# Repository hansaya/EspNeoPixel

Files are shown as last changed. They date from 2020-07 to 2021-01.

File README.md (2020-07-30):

# EspNeoPixel

Esp32 based neo pixel driver designed to work with WLED. 

# Thoughts behind my design
I recently discovered that [wled project](https://github.com/Aircoookie/WLED) works with [hyperion](https://hyperion-project.org/) and sparked my interest in building a unified system to tick off all the requirements. From previous experience with neo pixels, I knew I had to make sure to have a good power supply and a good logic level conversion to run the leds reliably. Power supply is the biggest thing to tackle and for it I have tried many off the shelve converters but most either bulky or cannot run at specified rating. You could buy a AC to DC converts thats rated for the led without using dc-dc converter but either they are expensive or have to compromise in quality. I decided to design my board around ~20V input because I have many old laptop power bricks collecting dust that can handle at least 100W each. They are safe and can find in many shape and sizes. If you don't have one, you can easily obtain one through ebay. 

Features:
* Buck converter, 8-24V input to 5v or 12v output to drive the led strips.
* Up to 10A output current.
* Level converter to drive the data and clock singles at 5v.
* Button connected to GPIO0. This can be used within wled to turn off the output.
* Capability to turn off the output using wled relay output.
* Push in terminal connectors for quick connections.

# Board

Use zip file within /cam folder to fabricate the board using your favorite pcb house. Bom contains the parts list. Please note, I have not listed out all parts since I had most 0603 jelly beans parts at home. Use the schematic to get the full list.

Enjoy!

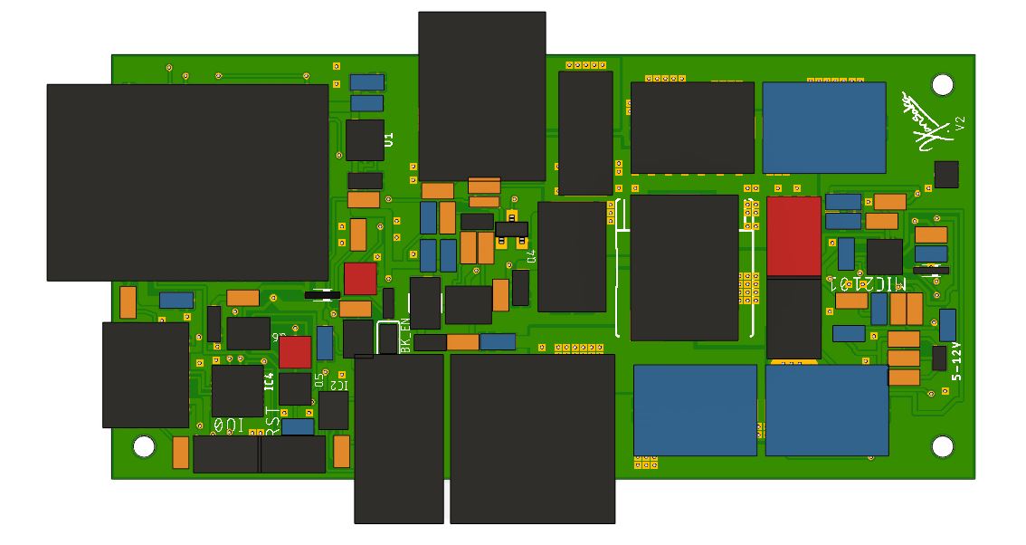
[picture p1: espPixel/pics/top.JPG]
Top side of the board

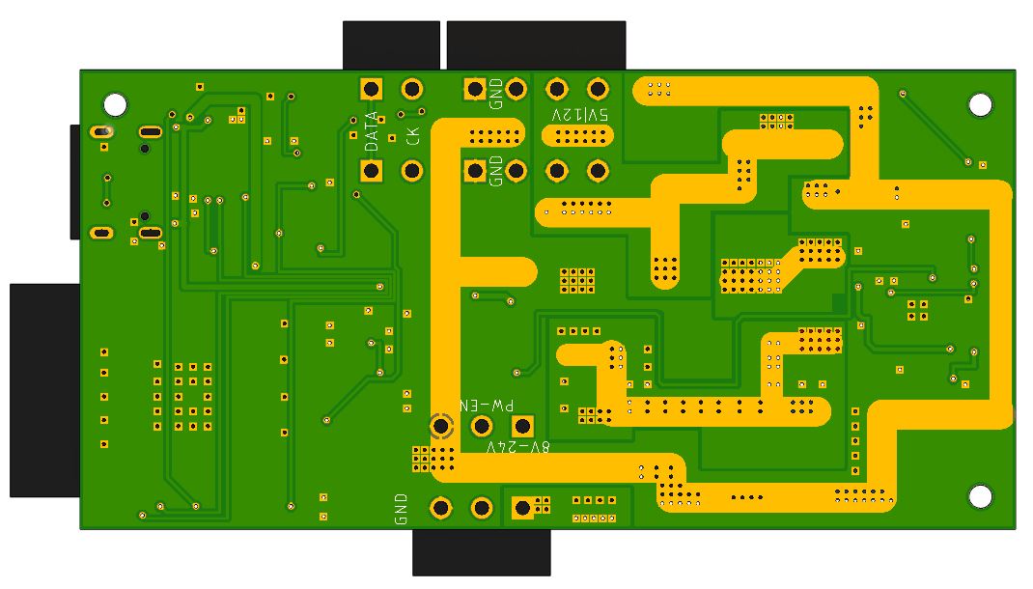
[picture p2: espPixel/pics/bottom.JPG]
Bottom side of the board

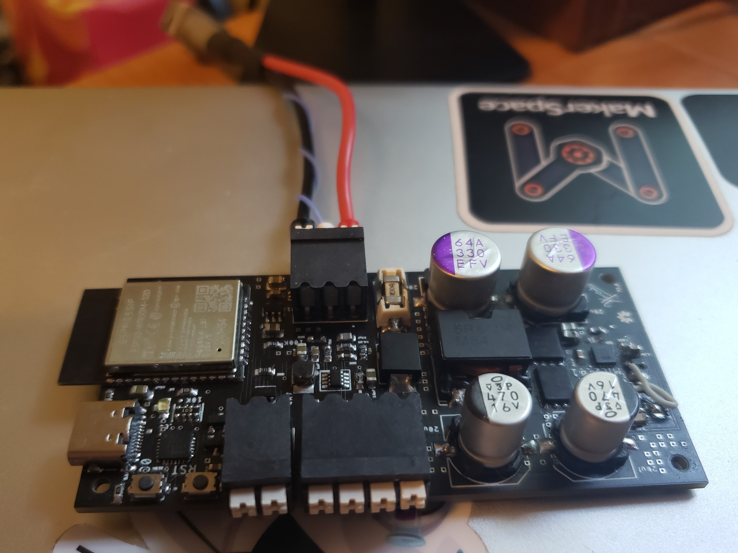
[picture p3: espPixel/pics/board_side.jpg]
Populated board


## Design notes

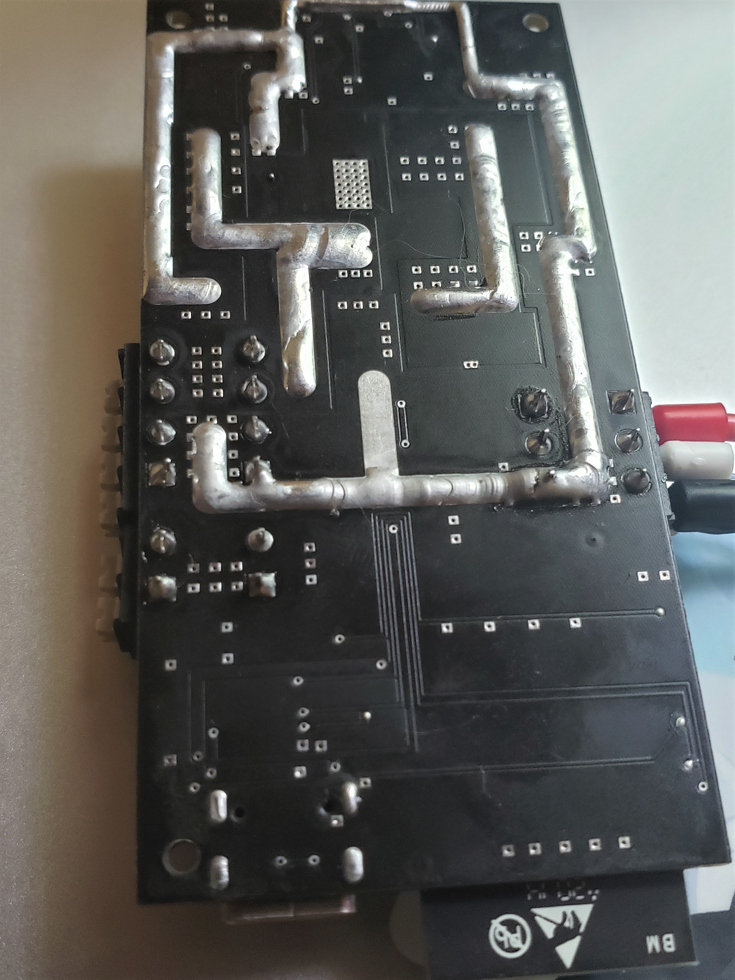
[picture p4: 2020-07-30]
espPixel/pics/board_back.jpg

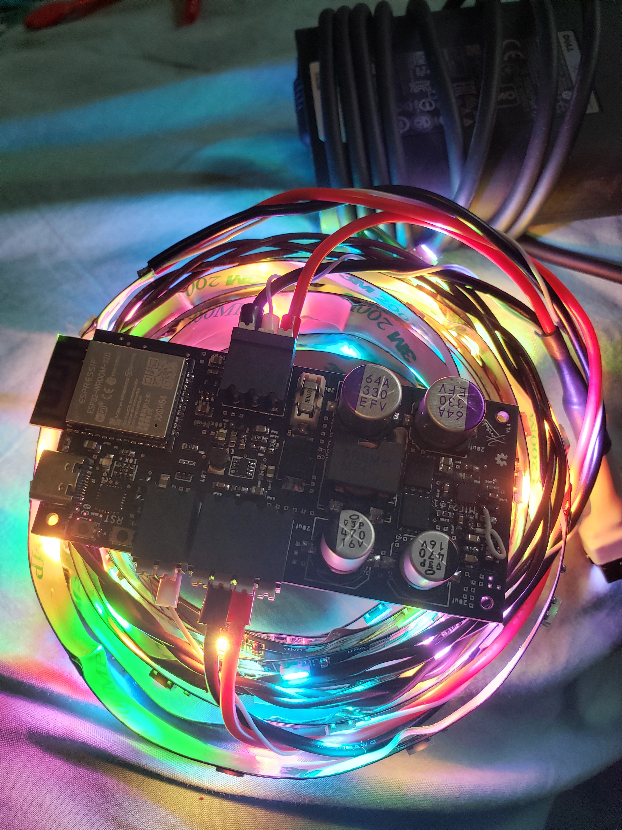
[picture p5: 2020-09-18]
espPixel/pics/running_wled.jpg

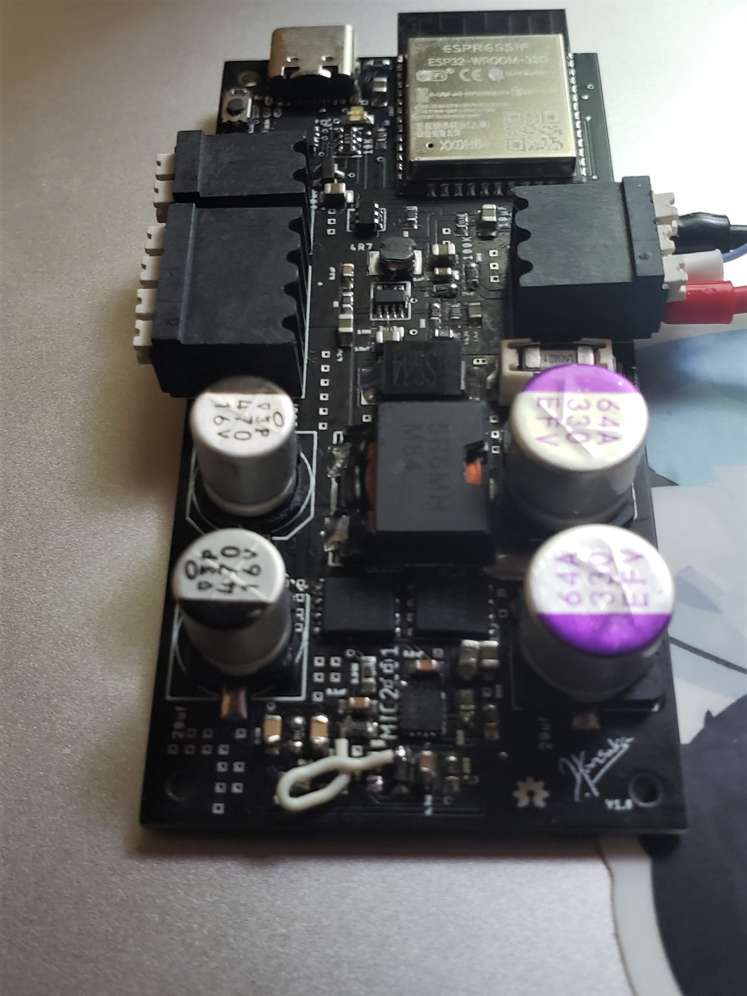
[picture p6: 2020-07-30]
espPixel/pics/board_top.jpg

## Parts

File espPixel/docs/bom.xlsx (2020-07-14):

Part name | Part number | price | location
Level shifter | 74LVC1T45W6-7 | 0.27 | https://www.digikey.com/product-detail/en/diodes-incorporated/74LVC1T45W6-7/74LVC1T45W6-7DICT-ND/8283861
4pin connector | TBLH10-350-04BK | 1.55 | https://www.digikey.com/product-detail/en/TBLH10-350-04BK/102-TBLH10-350-04BK-ND/10441921/?itemSeq=331108432
3pin connector | TBLH10-350-03BK | 1.33 | https://www.digikey.com/product-detail/en/cui-devices/TBLH10-350-03BK/102-TBLH10-350-03BK-ND/10442185
2pin connector | TBLH10-350-02BK | 1.02 | https://www.digikey.com/product-detail/en/TBLH10-350-02BK/102-TBLH10-350-02BK-ND/10442183/?itemSeq=331108581
649ohm | RMCF0603FT649RCT-ND‎ | 0.00292 | https://www.digikey.com/product-detail/en/RMCF0603FT649R/RMCF0603FT649RCT-ND/2418115/?itemSeq=331108552
3.48K ohm | RMCF0603FT3K48 | 0.1 | https://www.digikey.com/product-detail/en/RMCF0603FT3K48/RMCF0603FT3K48CT-ND/1943027/?itemSeq=331108413
9.09K ohm | RMCF0603FT9K09 | 0.1 | https://www.digikey.com/product-detail/en/stackpole-electronics-inc/RMCF0603FT9K09/RMCF0603FT9K09CT-ND/1943054
Inductor 4.7UH | CEP125NP 4.7UH | 11.7/10 | https://www.aliexpress.com/item/32839370463.html?spm=a2g0s.9042311.0.0.35f14c4dAlGctQ
ESP32 | ESP32-WROOM-32D | 2.37
1808 Fuse holder | 1808/2410 fuse holder | 0.2 | https://www.aliexpress.com/item/4000013163243.html?spm=a2g0s.9042311.0.0.4fa64c4dJv0TfD
1808 Fuse | 1808 Fuse | 0.2
5v Buck converter | MP2315 | 0.2 | https://www.aliexpress.com/item/32899141853.html
3.3 LDO | AP2112-3.3 | 0.47 | https://www.digikey.com/product-detail/en/diodes-incorporated/AP2112K-3-3TRG1/AP2112K-3-3TRG1DICT-ND/4505257
10A Buck converter | MIC2101 | 1.1 | https://www.digikey.com/product-detail/en/microchip-technology/MIC2101YML-TR/576-4154-1-ND/3681253
Push Buttons | 2Pin 3X4MM Tactile | 0.05 | https://www.ebay.com/itm/50PCS-SMD-2Pin-3X4MM-Tactile-Tact-Push-Button-Micro-Switch-Momentary/114266539434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
USB-C port | USB 3.1 Type C 16 Pin | 0.2 | https://www.ebay.com/itm/50PCS-USB-3-1-Type-C-4-Legs-16-Pin-Female-Socket-PCB-Solder-Connector-SMT/183702842042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
USB to Serial | CP2104 | 1.5 | https://www.digikey.com/product-detail/en/silicon-labs/CP2104-F03-GMR/336-4146-2-ND/4069045
10K Resistor array | CAY16-103J4LF | 0.1 | https://www.digikey.com/product-detail/en/bourns-inc/CAY16-103J4LF/CAY16-103J4LFCT-ND/3437832
Total |  | 10.76292

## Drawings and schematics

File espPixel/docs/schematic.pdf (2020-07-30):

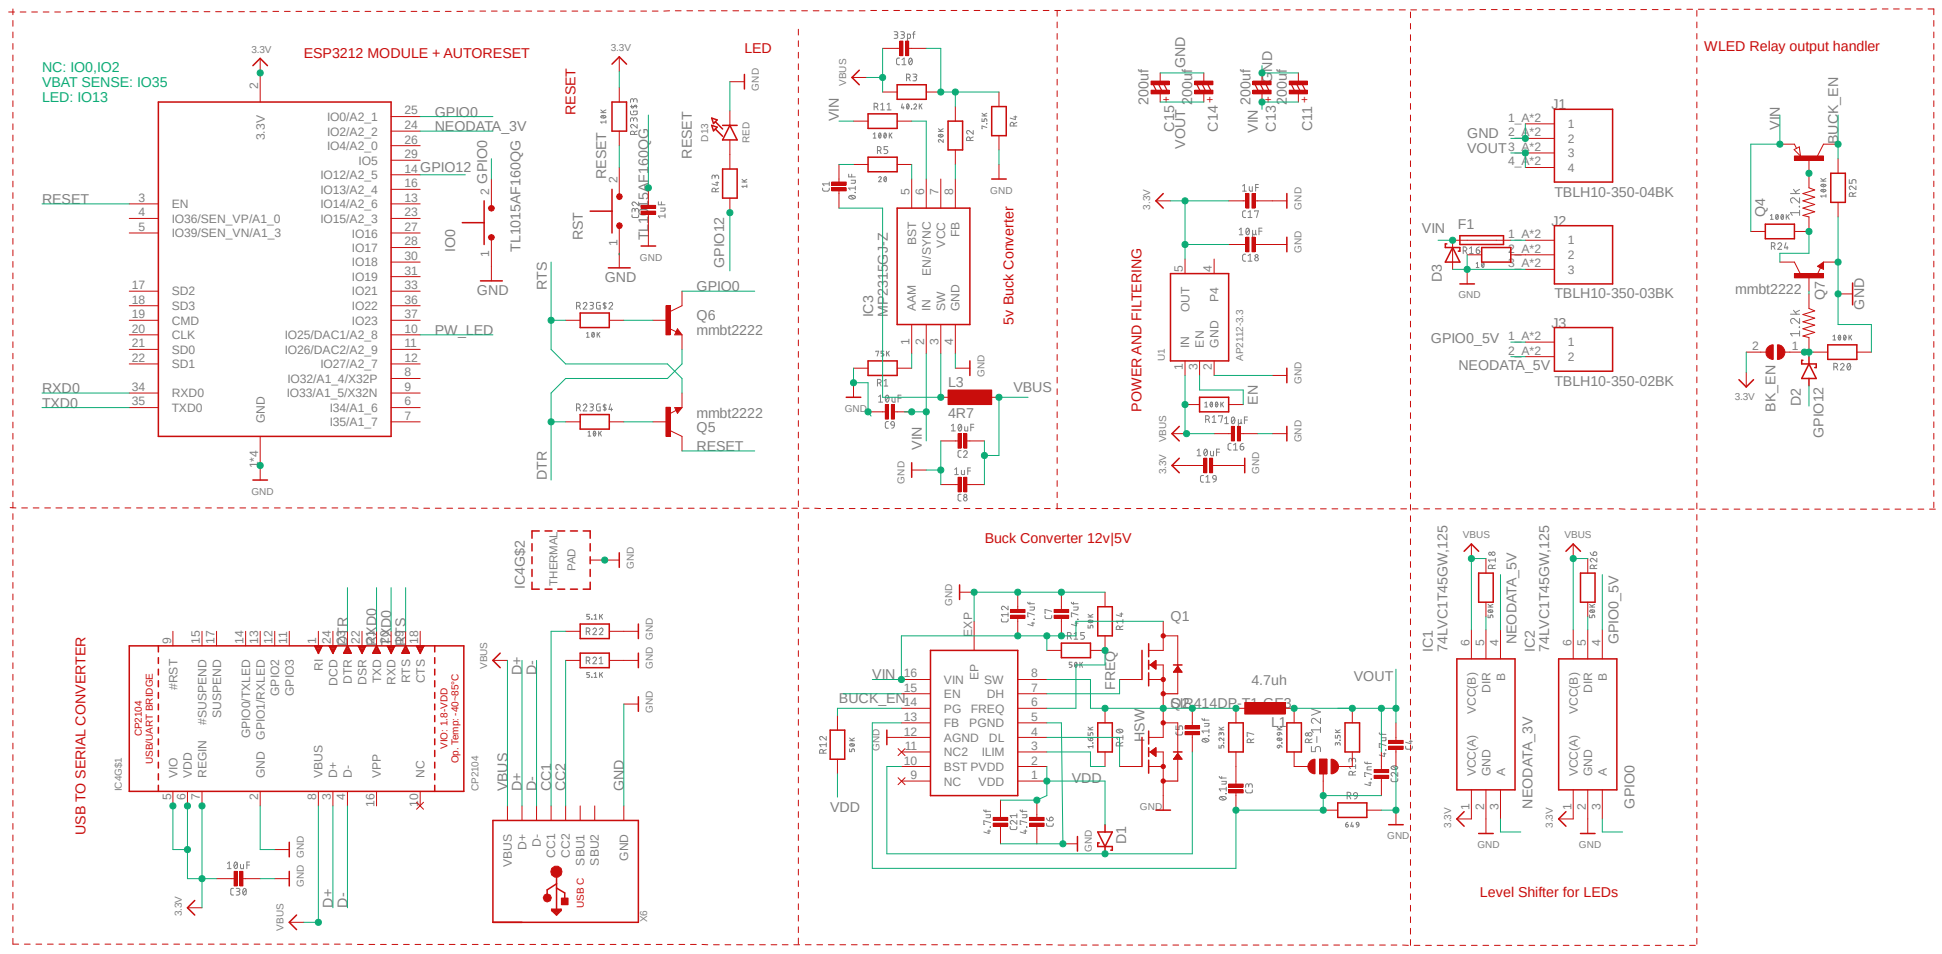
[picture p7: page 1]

4IC2 GND GND GND GND

WLED Relay output handler +

+ CP2104 USB/UART BRIDGE VIO: 1.8-VDD Op. Temp: -40~85°C USB C

9 NC 10 GPIO3 11 GPIO2 12 DCD 24 DTR 23 DSR 22 TXD 21 RXD 20 RTS 19 CTS 18 SUSPEND 17 VPP 16 #SUSPEND 15 GPIO0/TXLED 14 GPIO1/RXLED 13 IC4G$1 THERMAL PAD IC4G$2 D+D- VBUS CC1 GND SBU1 CC2 SBU2 X6 D13 1 2 RST 1 2 IO0 Q4

Level Shifter for LEDs

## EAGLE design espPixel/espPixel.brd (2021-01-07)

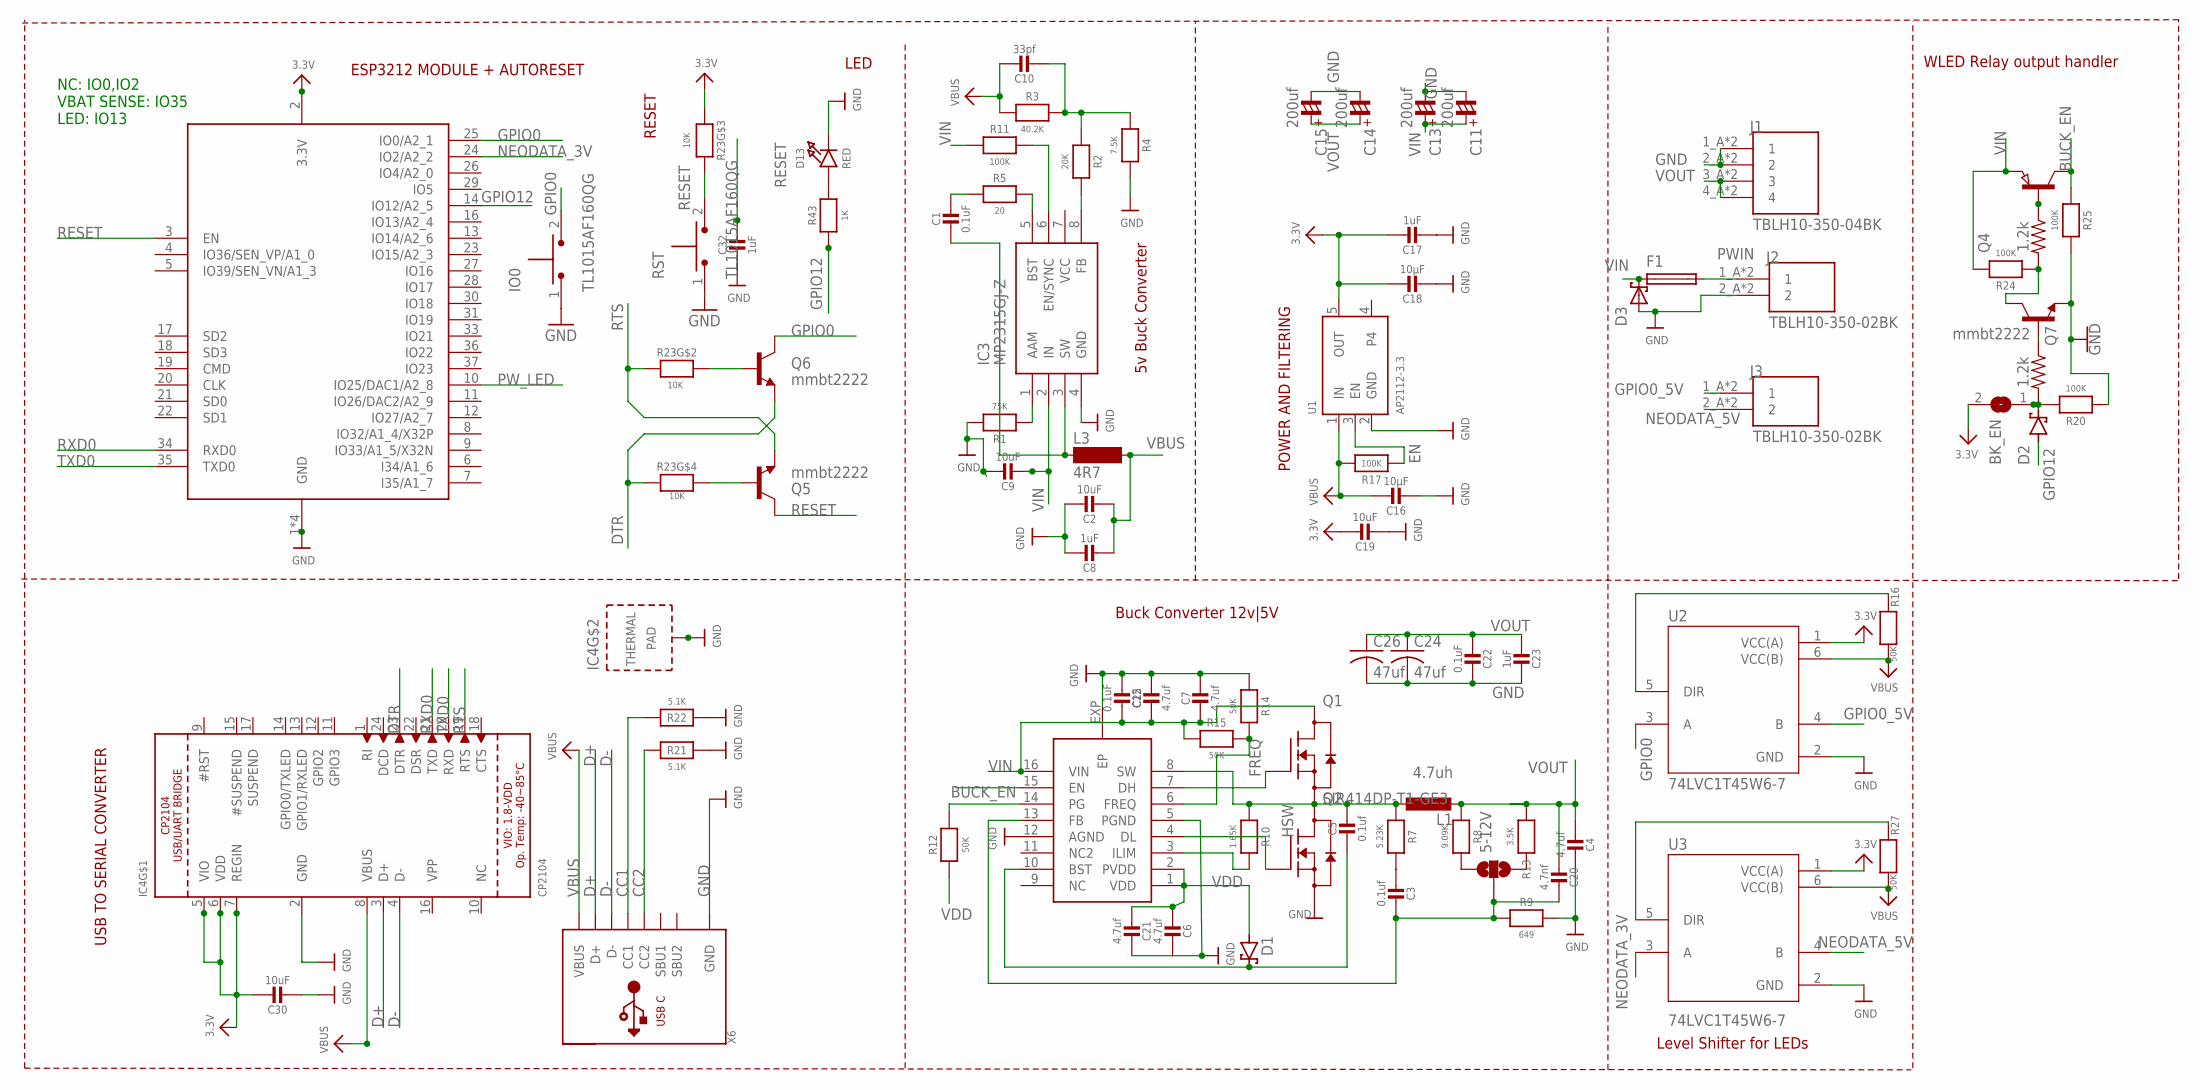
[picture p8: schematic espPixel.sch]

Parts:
5-12V: JUMPER-SMT_3_NO_NO-SILK; SMT-JUMPER_3_NO_NO-SILK
BK_EN: SJ
C1, C22, C25: 0.1uF; 0603-NO@1
C2: 10uF; 0603-NO@1
C3, C5: 0.1uf; 0603-NO@1
C4, C7, C12: 4.7uf; 0805_10MGAP
C6, C21: 4.7uf; 0603-NO@1
C8, C17, C23, C32: 1uF; 0603-NO@1
C9: 10uF; 0805_10MGAP
C10: 33pf; 0603-NO@1
C11, C13, C14, C15: 200uf; CSV-E/F
C16, C18: 10µF; 0805-NO
C19, C30: 10uF; 0805-NO
C20: 4.7nf; 0603-NO@1
C24, C26: 47uf; C3225
D1, D2: BAT60J; SOD323_ST
D3: SCHOTTKY-DIODESMC; SMC
D13: RED; CHIPLED_0805_NOOUTLINE
F1: SMD-MICRO-FUSE-BLOCK; OMNIBLOK
IC3: MP2315GJ-Z; SOT65P280X100-8N
IC4: CP2104; QFN24_4MM_SMSC
IO0: TL1015AF160QG; SW_TL1015AF160QG
J1: TBLH10-350-04BK; CUI_TBLH10-350-04BK
J2, J3: TBLH10-350-02BK; CUI_TBLH10-350-02BK
L1: 4.7uh; CEP125
L3: 4R7; MS50
Q1, Q2: SIR414DP-T1-GE3; TRANS_SQJ461EP-T1-GE3
Q4: PNP-TRANSISTOR_SOT23; SOT23
Q5, Q6, Q7: mmbt2222; SOT23-3
R1: 75K; 0603-NO
R2: 20K; 0603-NO
R3: 40.2K; 0603-NO
R4: 7.5K; 0603-NO
R5: 20; 0603-NO
R6, R19: 1.2k; 0603
R7: 5.23K; 0603-NO
R8: 9.09K; 0603-NO
R9: 649; 0603-NO
R10: 1.65K; 0603-NO
R11, R17, R20, R24, R25: 100K; 0603-NO
R12, R14, R15, R16, R27: 50K; 0603-NO
R13: 3.5K; 0603-NO
R21, R22: 5.1K; 0603-NO
R23: 10K; RESPACK_4X0603
R43: 1K; 0603-NO
RST: TL1015AF160QG; SW_TL1015AF160QG
U1: AP2112-3.3; SOT23-5
U2, U3: 74LVC1T45W6-7; SOT95P285X140-6N
U$1: MIC2101QFN16; QFN16
X6: USB_C; USB_C_CUSB31-CFM2AX-01-X
X8: ESP32_WROOM32_SKINNY; WROOM32_SKINNY

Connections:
3.3V: BK_EN.2, C17.1, C18.1, C19.1, C30.1, IC4.5 (VIO), IC4.6 (VDD), IC4.7 (REGIN), R23.3 (1), U1.5 (OUT), U2.1 (VCC(A)), U3.1 (VCC(A)), X8.2 (3.3V)
BUCK_EN: Q4.3 (C), R25.1, U$1.15 (EN)
CC1: R22.2, X6.A5 (CC1)
CC2: R21.2, X6.B5 (CC2)
D+: IC4.3 (D+), X6.A6 (D+), X6.B6 (D+)
D-: IC4.4 (D-), X6.A7 (D-), X6.B7 (D-)
DTR: IC4.23 (DTR), Q6.2 (E), R23.4 (1)
EN: R17.1, U1.3 (EN)
FREQ: R14.2, R15.2, U$1.6 (FREQ)
GND: C2.1, C4.1, C6.1, C7.1, C8.1, C9.1, C11.-, C12.1, C13.-, C14.-, C15.-, C16.2, C17.2, C18.2, C19.2, C21.1, C22.1, C23.1, C24.2, C25.2, C26.2, C30.2, C32.2, D3.A, D13.C, IC3.4 (GND), IC4.2 (GND), IC4.THERM (TP), IO0.1, J1.1_A (1), J1.1_B (1), J1.2_A (2), J1.2_B (2), J2.2_A (2), J2.2_B (2), Q2.1 (S), Q2.2 (S), Q2.3 (S), Q7.2 (E), R1.2, R4.2, R9.2, R14.1, R20.1, R21.1, R22.1, R25.2, RST.1, U1.2 (GND), U2.2 (GND), U3.2 (GND), U$1.5 (PGND), U$1.12 (AGND), U$1.EXP (EP), X6.A1B12 (GND), X6.B1A12 (GND), X8.1 (GND), X8.15 (GND), X8.38 (GND), X8.P$1 (GND)
GPIO0: IO0.2, Q6.3 (C), U2.3 (A), X8.25 (IO0/A2_1)
GPIO0_5V: J3.1_A (1), J3.1_B (1), U2.4 (B)
GPIO12: D2.A, R43.1, X8.14 (IO12/A2_5)
HSW: C5.1, L1.1, Q1.1 (S), Q1.2 (S), Q1.3 (S), Q2.5 (D), Q2.6 (D), Q2.7 (D), Q2.8 (D), Q2.9 (D), R7.1, R10.1, U$1.8 (SW)
unnamed: IC3.8 (FB), R2.2
unnamed: C10.2, R2.1, R3.2, R4.1
unnamed: IC3.5 (BST), R5.2
unnamed: IC3.1 (AAM), R1.1
unnamed: IC3.6 (EN/SYNC), R11.2
unnamed: C1.1, R5.1
unnamed: R12.2, U$1.14 (PG)
unnamed: C3.2, R7.2
unnamed: BK_EN.1, D2.C, R6.2, R20.2
unnamed: R27.1, U3.5 (DIR)
unnamed: 5-12V.2, C3.1, C20.1, R9.1, U$1.13 (FB)
unnamed: Q2.4 (G), U$1.4 (DL)
unnamed: Q1.4 (G), U$1.7 (DH)
unnamed: R10.2, U$1.3 (ILIM)
unnamed: C5.2, D1.C, U$1.10 (BST)
unnamed: 5-12V.1, R8.2
unnamed: 5-12V.3, R13.2
unnamed: D13.A, R43.2
unnamed: Q7.1 (B), R6.1
unnamed: Q4.1 (B), R19.1
unnamed: C1.2, IC3.3 (SW), L3.1
unnamed: Q7.3 (C), R19.2, R24.1
unnamed: R16.1, U2.5 (DIR)
unnamed: Q5.1 (B), R23.5 (2)
unnamed: Q6.1 (B), R23.7 (2)
NEODATA_3V: U3.3 (A), X8.24 (IO2/A2_2)
NEODATA_5V: J3.2_A (2), J3.2_B (2), U3.4 (B)
PWIN: F1.P$1 (1), J2.1_A (1), J2.1_B (1)
PW_LED: X8.10 (IO25/DAC1/A2_8)
RESET: C32.1, Q5.3 (C), R23.6 (2), RST.2, X8.3 (EN)
RTS: IC4.19 (RTS), Q5.2 (E), R23.2 (1)
RXD0: IC4.21 (TXD), X8.34 (RXD0)
TXD0: IC4.20 (RXD), X8.35 (TXD0)
VBUS: C2.2, C8.2, C10.1, C16.1, IC4.8 (VBUS), L3.2, R3.1, R16.2, R17.2, R27.2, U1.1 (IN), U2.6 (VCC(B)), U3.6 (VCC(B)), X6.A4B9 (VBUS), X6.B4A9 (VBUS)
VDD: C6.2, C21.2, D1.A, R12.1, U$1.1 (VDD), U$1.2 (PVDD)
VIN: C7.2, C9.2, C11.+, C12.2, C13.+, C25.1, D3.C, F1.P$2 (2), IC3.2 (IN), Q1.5 (D), Q1.6 (D), Q1.7 (D), Q1.8 (D), Q1.9 (D), Q4.2 (E), R11.1, R15.1, R24.2, U$1.16 (VIN)
VOUT: C4.2, C14.+, C15.+, C20.2, C22.2, C23.2, C24.1, C26.1, J1.3_A (3), J1.3_B (3), J1.4_A (4), J1.4_B (4), L1.2, R8.1, R13.1

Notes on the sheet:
5v Buck Converter
POWER AND FILTERING
ESP3212 MODULE + AUTORESET
NC: IO0,IO2 VBAT SENSE: IO35 LED: IO13
USB TO SERIAL CONVERTER
RESET
LED
Buck Converter 12v|5V
Level Shifter for LEDs
WLED Relay output handler

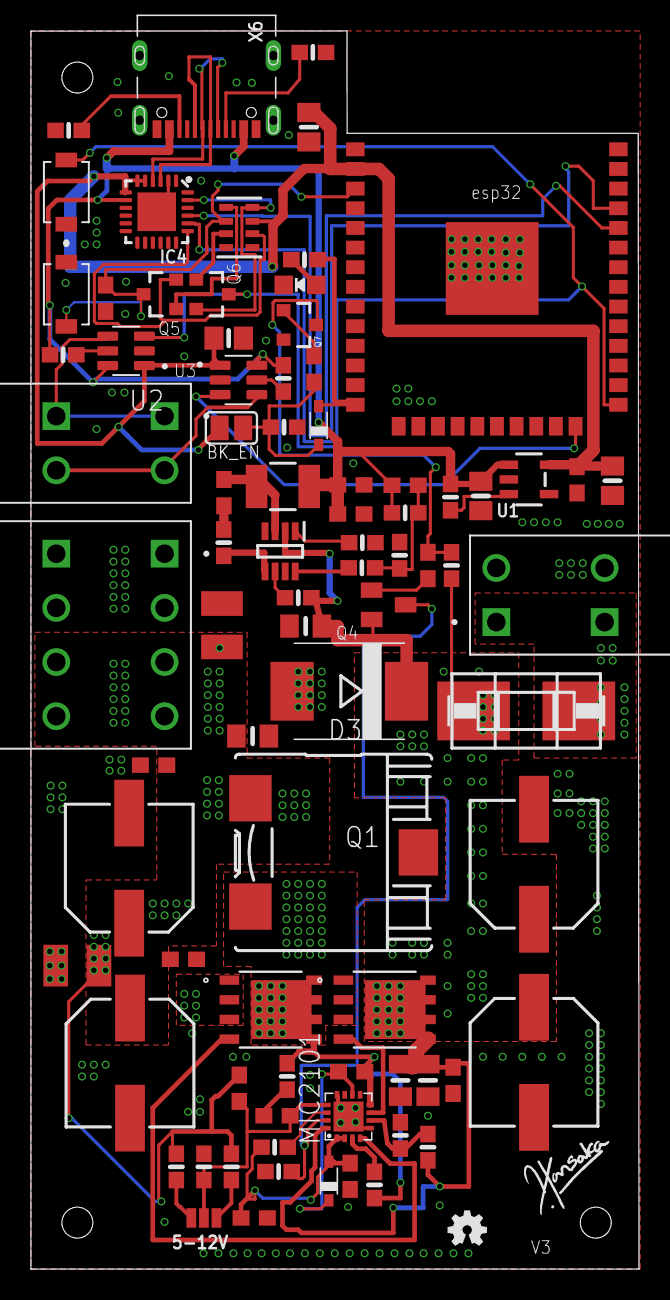
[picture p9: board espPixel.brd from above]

Board: 2 copper layers, 39.3 x 80.0 mm, 84 parts (0 on the bottom side), 50 nets.

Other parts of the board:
U$30: OSHW-LOGO-MINI
U$33: SIGNATURE

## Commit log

2020-07-01 final board files
    [espPixel.brd, espPixel.sch]
2020-07-14 bug fix
    [espPixel.brd, espPixel.sch]
2020-07-14 Text clean up
    [espPixel.brd, espPixel.sch]
2020-07-14 parts list update
    [pibom.xlsx]
2020-07-15 ability to turn off the output
    [espPixel.brd, espPixel.sch]
2020-07-16 bigger caps
    [espPixel.brd, espPixel.sch]
2020-07-22 clean up
    [espPixel.brd, espPixel.sch]
2020-07-30 finalizing the design
    [espPixel.brd, espPixel.sch]
2020-09-18 More filter caps
    [espPixel.brd, espPixel.sch]
2021-01-07 v3 more compact size
    [espPixel.brd, espPixel.sch]

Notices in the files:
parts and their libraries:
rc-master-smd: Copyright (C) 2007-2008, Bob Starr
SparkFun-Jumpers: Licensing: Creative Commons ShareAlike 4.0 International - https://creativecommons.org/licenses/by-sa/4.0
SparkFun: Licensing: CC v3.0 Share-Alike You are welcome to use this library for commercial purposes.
